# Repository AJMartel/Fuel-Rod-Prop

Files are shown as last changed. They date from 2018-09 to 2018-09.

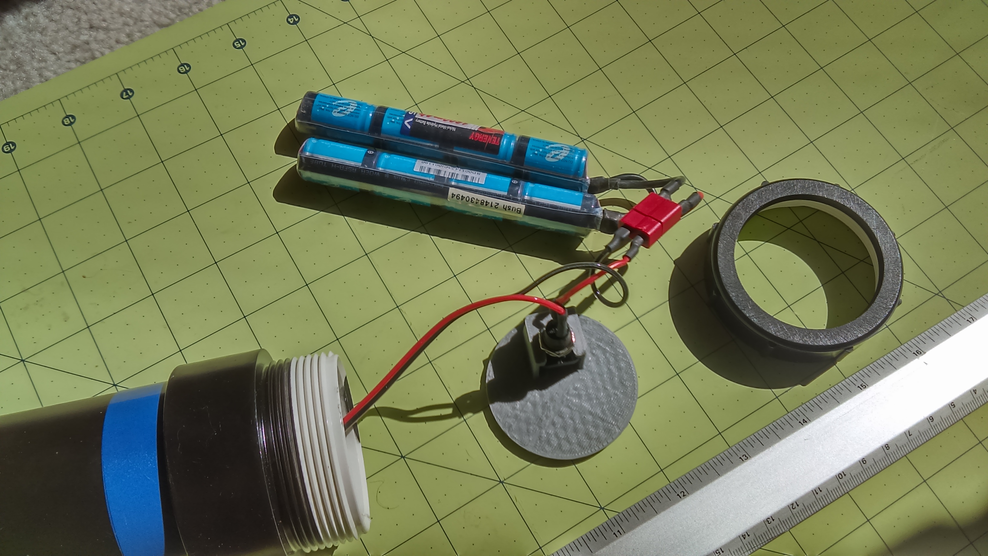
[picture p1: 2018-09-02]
IMAG0169.jpg

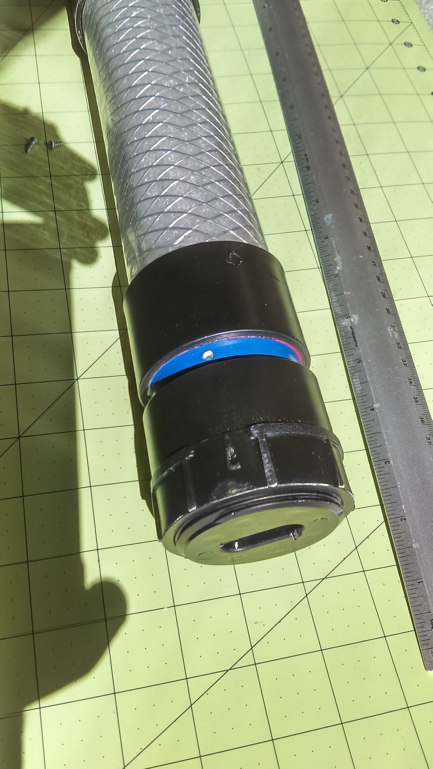
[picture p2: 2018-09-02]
IMAG0179.jpg

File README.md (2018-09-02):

# Fuel-Rod-Prop
An airsoft in game prop styled like a fuel rod.

This prop has 6 different modes of operation depending on what fits the game play best.

It responds to shock and beeps or displays different colored lighting. 

It can be used with the BoomBox prop as well to simulate fuel loading or unloading, if a multi-step goal is required for a game scenario.

The prop has no visible switches – the main power switch is a pushbutton that requires a 1-2”
pin to depress (thru a hole on the end). The unit senses shock and is programmed by
“tapping” it during program mode. Other magnetic sensors are used to “charge” the fuel or
discharge the fuel, and if the charging base isn't handy any high strength magnet can be used
to trip the internal reed switches. By using hidden magnetic switches, the unit is more rugged,
tamper-proof, and weather resistant. 

Note that this will probably not be improved upon or built (by me at least) again, but as i used several resources from others across the net when designing and constructing the device, i wanted to share the results with everyone as well.

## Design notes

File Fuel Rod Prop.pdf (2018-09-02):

Fuel Rod Prop Operation

The prop has no visible switches – the main power switch is a pushbutton that requires a 1-2” pin to depress (thru a hole on the end). The unit senses shock and is programmed by “tapping” it during program mode. Other magnetic sensors are used to “charge” the fuel or discharge the fuel, and if the charging base isn't handy any high strength magnet can be used to trip the internal reed switches. By using hidden magnetic switches, the unit is more rugged, tamper-proof, and weather resistant. Note that it is not waterproof however and should not be used in heavy rain or immersed.

If the unit is ever in heavy rain or immersed, be sure to unscrew the key switch end of the device and unplug the battery as soon as possible.

The unit will provide feedback when a hidden switch is tripped by LED color changes or beeper sounds.

If the fuel rod has been modified to work with the BoomBox, there will be an additional high strength magnet in the top (the longer black part) of the unit on the same side as the magnet sensor. This is used to tell the BoomBox the fuel rod is present.

Theory of operation

The prop is designed to mimic a “fuel rod” or a “mutagen container” from popular movies. It does not explode, but it does challenge the players in other ways depending on game mode:

1. The prop can require “charging” before it can be used.
2. The prop can “decay” once charged, requiring players to complete a task within a specific number of minutes (this is set in programming and not easily changed in the field). If the unit decays it must be recharged. As it decays the LEDs change from a green “charged” state to a blue “cold/dead” state.
3. The prop can become “unstable” if shaken or shocked too much. As the prop becomes more unstable it changes from Green to Red color.
4. The prop can be set to go inert if it is pushed into the unstable zone too many times. Once it goes inert, it must be recharged to be used.
5. The prop can be set to “lost” mode where it blinks and beeps once every couple seconds, making it harder to find at night or in a search and recover game mode.
6. The sensitivity can be set to different levels to make it more or less challenging to players.

If players have problems remembering what colors do what, just remind them that “GREEN IS GOOD”. Meaning a GREEN fuel rod is charged and not unstable or blown. BLUE is COLD, meaning not charged or primed (this isn’t necessarily bad, it depends on the game mode). RED is BAD, cause it means the device is exploded or abused.

Programming Modes

There are several game modes. The second mode is DEMO mode, where charging, decay, shaking and making it go inert can be demonstrated quickly. The third mode is a sensitivity setting mode, where the admin can bump or tap the prop harder or softer (or not at all) to set sensitivity to shock. All other modes differ in options – such as whether shaking can make it go inert or how long a decay takes, if decay is even enabled.

To enter program mode, turn on the device, let it initialize. It will quickly beep the number of times corresponding to the currently set game mode (i.e. 7 beeps = game mode 7, BoomBox Prop). The white LEDs will also show mode (in binary). After beeping stops, while the unit is still white, you can change the mode by tapping the unit. Each tap will advance in modes and beep the same number of times as the mode. The LED display will show (in binary) what number mode is active, with the power switch end as the lowest bit (right =1, middle=2, left =4, add the values to get your number).

Once you pass the last mode, the unit starts at mode 1 again. Once you reach the mode you want, leave the unit alone for 5 seconds and that mode will be set.

Note – This takes some practice to get used to. You should go thru the programming process a few times to get used to it. It is probably also in your best interest to hide the program modes and power switch from the players.

Mode Details

1. Resupply Safe Mode. Starts uncharged, Decays in 30 minutes, More than 5 red zones disables.
2. DEMO mode. Starts uncharged (BLUE). Place in charging base or hold magnet near charge sensor to 'charge' to GREEN. You have 1 minute to demonstrate the shock sensing (tap it to show it turning YELLOW then RED). As the time passes the unit decays from GREEN to BLUE. If you shake the unit enough it will become unstable and blink RED and flash and beep, then go inert (BLUE). You can recharge the unit if needed.
3. Sensitivity Setting. When the unit changes to 1 white LED color, you have 5 seconds to set the sensitivity by bumping the unit with harder or lighter force. Anything harder than how you bump the device will be seen as a valid shock and push the unit into instability. To set the unit to highest sensitivity, enter the sensitivity mode and do not bump or shock the prop at all.
4. Search N Rescue. Unit needs to be set to this mode (or powered up) then carefully set in the grass or on the ground, as it uses max sensitivity at first to detect being picked up. Unit beeps every so often to aid in location. When picked up, it senses this, and starts a countdown. Get the unit to a base to discharge it (or, deliver the goods before they expire). This mode might also be useful to give the BoomBox an initial charge. It will not, however, respond if used to disarm the BoomBox (but it will work for that).
5. Hot Potato – Unit starts charged, but cant be “discharged”. Unit counts down time and explodes, or explodes if mishandled more than 5 times. To prevent explosion, the unit must be placed in a base or can slot before it detonates. This resets the timer to the start of the countdown. In effect.. the players have to keep the unit from exploding by putting it in bases. Admins could move one base around the field agter it is used to prevent an explosion to make game play more active…
6. Rush – Unit starts charged. Players have to overtake the base, and insert the fuel rod. They must then hold the base for 5 minutes to allow the rod to explode. Once exploded, the rod resets when removed from the base and is ready to be used on the next objective. Instead of “exploding” you could tell the players the fuel rod is a hacking tool that takes 5 minutes to complete, and they must take each building (order does not matter) across the field.
7. BoomBox Prop – Unit starts charged. When placed in the BoomBox slot (or a base) it discharges and waits for removal. 10 seconds after removal, it is ready to take the charge back from the BoomBox by being placed back into the fuel rod slot. While the BoomBox is disabled at this point, the fuel rod will continue to alternate between charged and discharged state. An admin could start this mode, discharge the rod with a magnet, then start a scenario with a charged BoomBox in the process of counting down and give the special team the fuel rod discharged, and ask them to disarm the bomb, then bring back the fuel (the rod will be green if charge is recovered). Or just use it to start the BoomBox prop by giving a charged rod to players to take to the device…
Mode | Initial Charge State | Decay | Shock Mode | Name
1 | NOT Charged | 30 Minutes | 5 Red Zones disables it | ReSupply Risky
2 | NOT Charged | 1 Minute | 2 Red Zones disables it | Demo Mode Sensitive
3 | n/a | n/a | Starts at Max, tapping sets to that level. | Sensitivity Setting
4 | Charged | 30 Minutes | Reacts, but wont die. | Search n Rescue
5 | Charged | 30 Minutes | 5 Red Zones disables it | Hot Potato
6 | Charged | 5 Minutes | Reacts, but wont die. | Rush
7 | Charged | n/a | Reacts, but wont die. | BoomBox Prop

Battery Charging

The unit uses any LiPo or NiMh battery that will fit, from 7.2V to 12v. The battery connector is a normal Deans connector for reliability (but the current draw is at most 300mA which is fairly small). There is no protection against over discharge, so be careful when using LiPOs.

A NiMh 9.6V is recommended.

To open the unit, unscrew the key switch end and remove the battery carefully, trying not to damage or pull on wires and cables if possible. When reassembling, ensure wires and components are not pinched.

Fuse

The unit uses an internal small glass 1A fuse.

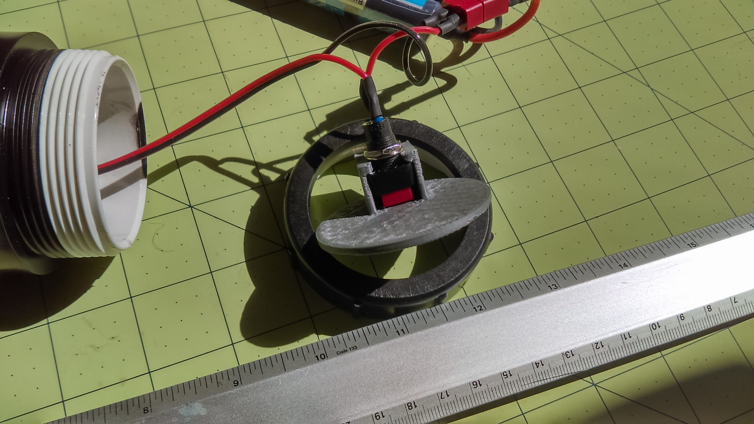
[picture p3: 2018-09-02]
IMAG0170.jpg

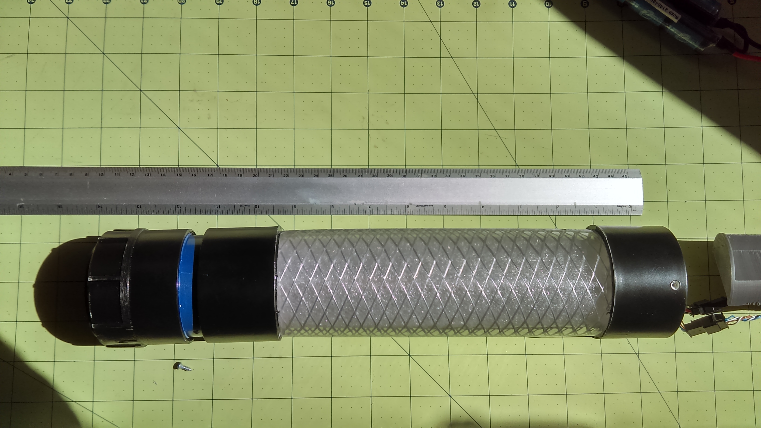
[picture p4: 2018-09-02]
IMAG0178.jpg

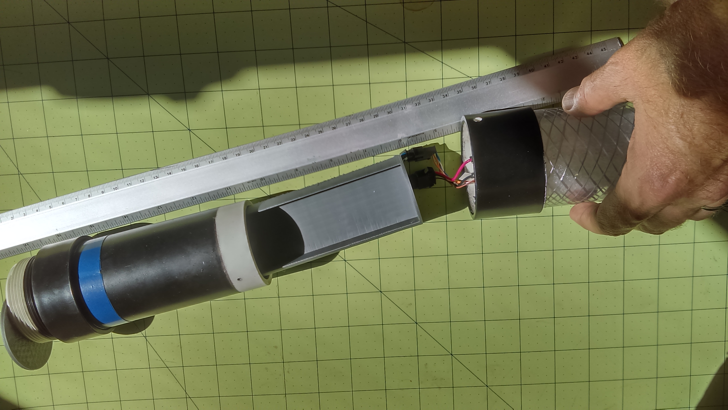
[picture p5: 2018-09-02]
IMAG0176.jpg

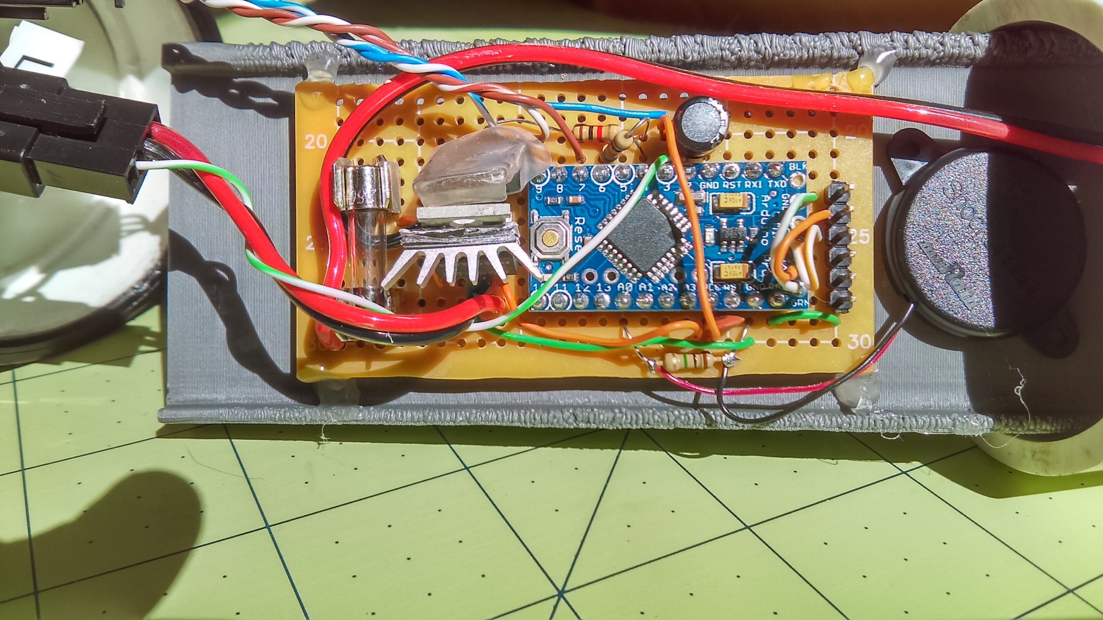
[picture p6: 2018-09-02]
IMAG0174.jpg

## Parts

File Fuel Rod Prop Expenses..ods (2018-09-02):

Item | Base Price | Qty | Amount | Total
Perfboard | 2.49 | 1 | $2.70 | $77.33
Black Paint (Fusion) | 4.94 | 0.3 | $1.60
Braided Vinyl Pipe | 8.98 | 0.5 | $4.86
2" DWV Coupling HXH 611942031900 | 1.26 | 1 | $1.36
2" PVC Coupling SXS 611942037643 | 1.96 | 1 | $2.12
2" DWV Male Adapter 611942032884 | 1.45 | 1 | $1.57
2" DWV Flush Cleanout Plug | 2.57 | 1 | $2.78
2" PVC Female Adapt | 1.88 | 1 | $2.04
NTE 74-5FG1A-B 1 Amp Fuse | 3.99 | 0.1 | $0.43
NTE 74-FC5-B Fuse Clips | 1.69 | 0.2 | $0.37
Philmore 30-100 Key Switch | 7.79 | 1 | $8.43
EvilMadScientist RGB LED Pixels | 10.99 | 0.9 | $10.71
Resistors (10k*2, 220*2, 1m) | 0.25 | 5 | $1.35
Arduino Pro Mini (Arducam) | 5.49 | 1 | $5.94
Screw Connectors | 0.5 | 4 | $2.17
10 ga Solid Wire |  | 1 | $-
Misc Connection Wire |  | 1 | $-
Solder |  | 1 | $-
Heat Shrink (1/2*2in, 1/4*4in) |  | 1 | $-
PVC Cement |  | 1 | $-
Screws |  | 1 | $-
SamariumCobalt Magnets (1 square, 2round) | 2 | 3 | $6.50
3D Print - Base, LED support top/bottom, keyswitch disc) ~75g-5h print time | 16 | 0.075 | $1.30
Piezo Sensor | 1 | 1 | $1.08
Reed Switches | 0.5 | 2 | $1.08
7.4v 1A-hr LiPo w/Deans | 15 | 1 | $16.24
Deans Male | 1.5 | 1 | $1.62
5V USB Power (Lighter Sicket, converted) | 1 | 1 | $1.08
Code Dev Time-Hours (actual * .3 factor for my non-expert skills? No idea what value is...) | 0 | 40 | $-
No documentation done yet. Code is unpublished, but commented.

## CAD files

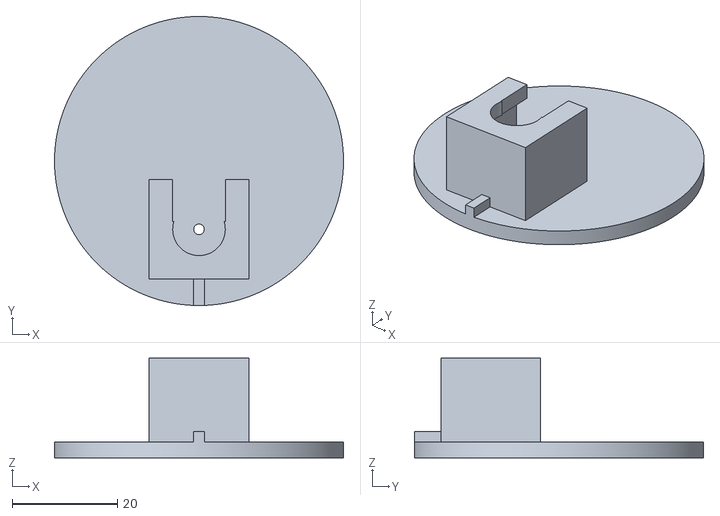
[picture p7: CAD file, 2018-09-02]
Fuel Rod Disc.stl
55.0 x 55.0 x 19.0

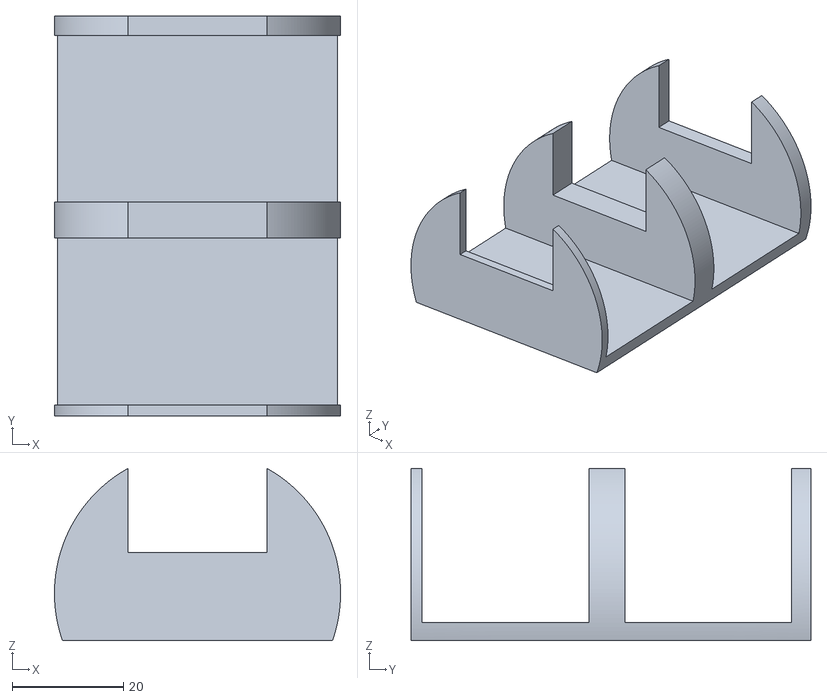
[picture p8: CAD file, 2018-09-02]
Fuel Rod Insert.stl
51.5 x 72.0 x 31.0

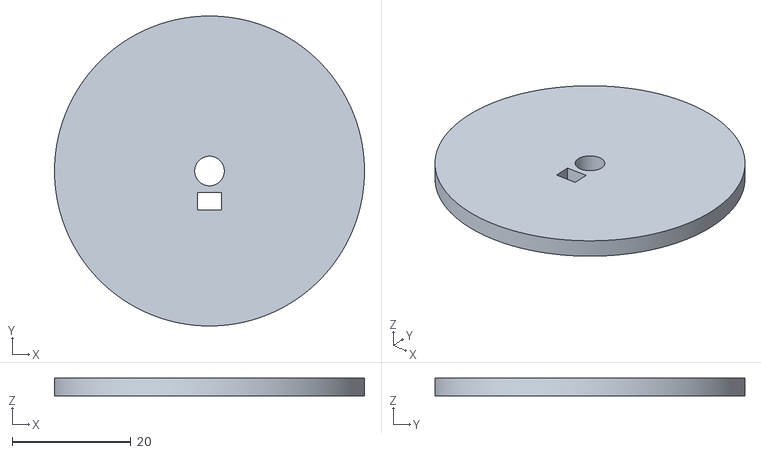
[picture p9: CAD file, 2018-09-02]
Fuel Rod Top LED Tube.stl
52.2 x 52.2 x 3.00

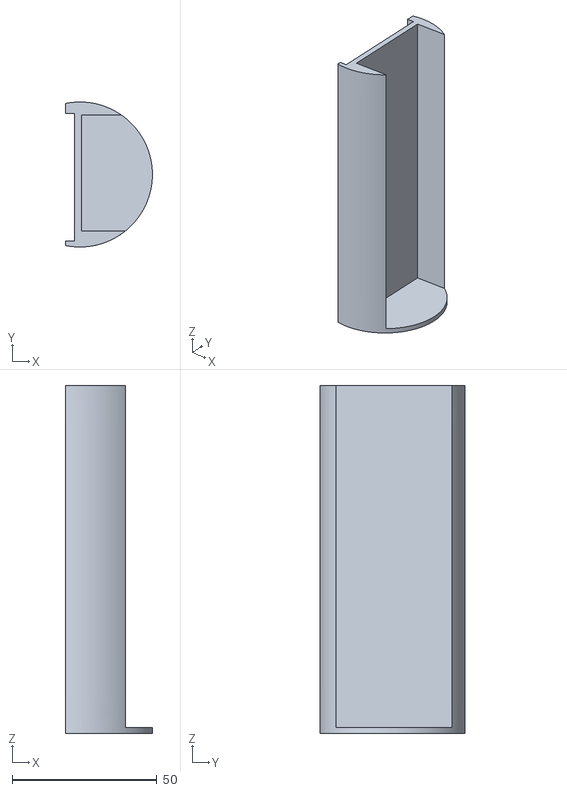
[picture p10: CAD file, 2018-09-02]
Fuel Rod NiMh Holder.stl
30.0 x 50.0 x 120.0

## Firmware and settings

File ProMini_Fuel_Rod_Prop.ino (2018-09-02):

/* Fuel Rod Prop Code v2.1
   Modes:
   1. ReSupply Risky. Uncharged, 30 minute decay, 5 Red events disables.
   2. Demo Mode, Uncharged, 1 m decay, 2 Red disables.
   3. Sensitivity Setting.
   4. Search N Rescue, Precharged, 30 m decay, 9999 Red events disables.
   5. Hot Potato, Precharged, 30 minute decay, 5 Red events disables.
   6. Rush, Precharged, 5 minute decay, 9999 Red events disables.
   7. BoomBox Prop, Precharged, 9999 no decay, 9999 Red events disables.
   
   Created: March 6, 2016
   Author: Reid Bush
*/
#include <WS2812.h>
#include <EEPROM.h>
const byte ledPIN = 2; // LED WS2812 on D2
const byte audioPIN = 4; // Audio Out on D4
const byte shakePIN = A0; // Shake Sensor on A0
const byte chargePIN = 6; // Charge Button on D6
const byte battPIN = A1; // Batt Sense on A1
byte gameMode = 1; // What game mode (see above) are we in?
byte instability = 0; // 0-255 0=calm 128=warn 250=red alert.
int redCount = 0; // How many red alerts we allow till fuel is tainted. Countdown style, default is 5.
int redLimit = 5; // How many red alerts we allow before discharging.
int threshold = 1; // Threshold for shake detection. 1=max sensitivity. Pull value from EEPROM initially.
int p = 20; // test charge loop delay
int s = 20; // test charge loop delay
byte eepromHigh = 0; // Value to hold EEPROM high byte.
byte eepromLow = 0; // Value to hold EEPROM low byte.
int decayTime = 0; // How long minutes we allow the fuel to last. 9999 = no decay.
unsigned long nextCalm = 0; // next millis to decrement instability.
unsigned long decayEndTime = 0; // Our fuel charge is decayed by this time.
unsigned long decayThirdTime = 0; // 1/3 Our fuel charge is decayed by this time.
unsigned long decay2ThirdTime = 0; // 2/3 Our fuel charge is decayed by this time.
unsigned long preProgTimeOut = 0; // Hold prog button until we reach this time to enter Prog Mode.
unsigned long nextFlash = 0; // Time when the next locate flash should occur.
bool countdown = false; // If on, we go from green to red and explode at end.
bool found = false; // true if the unit was found in S&R mode.
bool gameOn = false; // Is the game mode enabled?
bool charged = false; // Is the canister charged? (Green) or not (Blue)
bool redMode = false; // Are we in red mode?
bool needSensLearn = false; // Do we need to learn sensitivity again? default is to take last value from EEPROM.
bool progMode = false; // Are we in Prog mode?
bool led0Charged = false; // Track if LED0 can be shaken.
bool led1Charged = false; // Track if LED1 can be shaken.
WS2812 LED(3); // Set num of LEDs to 3
cRGB value;

void setup() {
  Serial.begin(9600);
  // Set up PIN functions.
  pinMode(audioPIN, OUTPUT);
  pinMode(shakePIN, OUTPUT);
  digitalWrite(shakePIN,LOW);
  pinMode(shakePIN, INPUT);
  pinMode(chargePIN, INPUT);
  pinMode(battPIN, INPUT);
  // Set remaining PINs to prevent quiescent current.
  pinMode(3, INPUT_PULLUP);
  pinMode(5, INPUT_PULLUP);
  pinMode(7, INPUT_PULLUP);
  pinMode(8, INPUT_PULLUP);
  pinMode(9, INPUT_PULLUP);
  pinMode(10, INPUT_PULLUP);
  pinMode(11, INPUT_PULLUP);
  pinMode(12, INPUT_PULLUP);
  pinMode(13, INPUT_PULLUP);
  pinMode(16, INPUT_PULLUP);
  pinMode(17, INPUT_PULLUP);
  // LED setup section.
  LED.setColorOrderRGB();
  LED.setOutput(ledPIN);
  // Get sensitivity setting from EEPROM if found.
  eepromHigh = EEPROM.read(0); 
  eepromLow = EEPROM.read(1);
  threshold = word(eepromHigh,eepromLow);
  if (threshold > 1024 || threshold < 1) {
    // value is invalid. May be corrupted or not initialzed yet. Default = 1
    threshold = 1;
    EEPROM.write(0,highByte(threshold));
    EEPROM.write(1,lowByte(threshold));
  }
  // Get last game setting from EEPROM if found.
  gameMode = EEPROM.read(2); 
  if (gameMode > 7 || gameMode < 1) {
    // value is invalid. May be corrupted or not initialzed yet. Default = 1
    gameMode = 1;
    EEPROM.write(2,gameMode);
  }
  // Notify that setup is complete.
  allLEDs(1);
  delay(200);
  allLEDs(0);
  Serial.println(F("Device is initialized."));
  Serial.println(F("Firmware 2.1"));
  Serial.print(F("Threshold: "));
  Serial.println(threshold);
  Serial.print(F("Game Mode:"));
  Serial.println(gameMode);
  preProgTimeOut = millis() + 10000; // We start the device in prog mode, and wait 10 seconds for a shock input to change modes.
  progMode = true;
  showMode(gameMode);
  for (int i = 0; i < gameMode; i++) {
    beep(80);
    delay(300);
  }
}


void loop() {
  // Program mode selection
  if (progMode) {
    int shakeValue = 0;
    shakeValue = analogRead(shakePIN);
    if (shakeValue > 10) { // something is bumping us, assume its a programming request.
      Serial.print("prog shake: ");
      Serial.println(shakeValue);
      gameMode ++;
      if (gameMode > 7) {
        gameMode = 1;
      }
      showMode(gameMode);
      for (int i = 0; i < gameMode; i++) {
        beep(80);
        delay(333);
        preProgTimeOut = millis() + 5000;
      }
    }
  }
      
  // No input pressed and we passed the Prog 10 sec timeout, set game values, exit progMode
  if (millis() > preProgTimeOut && progMode) { 
    progMode = false;
    preProgTimeOut = 0;
    decayEndTime = millis() + (decayTime * 60000);
    nextCalm = millis();
    instability = 0;
    // Common Variables set here. Change if needed for specific modes.
    countdown = false; // Rush mode 5 minute countdown to blow.
    needSensLearn = false;
    gameOn = true;
    EEPROM.write(2,gameMode);

    switch (gameMode) {
      case 1: // Resupply Risky Mode
        led0Charged = false;
        led1Charged = false;
        charged = false;
        decayTime = 30; // Normally 30
        redLimit = 5;
        Serial.println("Mode 1. ReSupply Safe.");
        break;
      case 2: // DEMO mode.
        led0Charged = false;
        led1Charged = false;
        charged = false;
        decayTime = 1;
        redLimit = 2;
        threshold = 1;
        Serial.println("Mode 2. DEMO.");
        break;
      case 3: // Sensitivity Set
        led0Charged = false;
        led1Charged = false;
        charged = false;
        decayTime = 9999;
        redLimit = 9999;
        needSensLearn = true;
        threshold = 1;
        gameOn = false;
        Serial.println("Mode 3. Sensitivity Set.");
        break;
      case 4:// Search & Rescue
        led0Charged = true;
        led1Charged = true;
        charged = true;
        decayTime = 30; // Normally 30
        redLimit = 9999;
        allLEDs(0);
        Serial.println("Mode 4. Search & Rescue.");
        break;
      case 5: // Hot Potato
        led0Charged = true;
        led1Charged = true;
        charged = true;
        decayTime = 30; // Normally 30
        redLimit = 5;
        allLEDs(4); // Green
        Serial.println("Mode 5. Hot Potato.");
        break;
      case 6: // Rush
        led0Charged = true;
        led1Charged = true;
        charged = true;
        allLEDs(4); // Green
        decayTime = 5;
        redLimit = 9999;
        Serial.println("Mode 6. Rush");
        break;
      case 7: // BoomBox Prop Mode
        led0Charged = true;
        led1Charged = true;
        charged = true;
        decayTime = 9999;
        redLimit = 9999;
        Serial.println("Mode 7. BoomBox Prop.");
        break;
    }
    redCount = redLimit;
    decayEndTime = millis() + (decayTime * 60000);
    decayThirdTime = millis() + (decayTime * 60000) / 3;
    decay2ThirdTime = millis() + (decayTime * 120000) / 3;
  }

  // Sensitivity setting requested (mode 2)
  if (needSensLearn) {
    learnShockLevel();
  }

  // Game mode processing
  if (gameOn) {
    switch (gameMode) {
      case 1: // Default Resupply Risky Mode uncharged, 5 red, 30m decay, discharges
        if (charged) {
          shakeProcess(); // Check for shaking and process
          if (redCount == 0) abused(1); // Check to see if device is abused and needs total discharge.
          decayLEDs(1); // Check for decay state and process
        } else {
          allLEDs(3); // Set LEDs blue
          if (digitalRead(chargePIN) == LOW) checkCharge(); // Check for charging base and process
        }
        break;
      case 2: // Demo Mode
        if (charged) {
          shakeProcess(); // Check for shaking and process
          if (redCount == 0) abused(1); // Check to see if device is abused and needs total discharge.
          decayLEDs(1); // Check for decay state and process
        } else {
          allLEDs(3); // Set LEDs blue
          if (digitalRead(chargePIN) == LOW) checkCharge(); // Check for charging base and process
        }
        break;
      case 4: // Search and Rescue Mode - 3 sec beep till shaken, then 25 mins decay till dies - in base wins.
        if (analogRead(shakePIN) > 2 && !found) { // something is bumping us, assume we have been picked up.
          Serial.println("Found! Starting countdown.");
          found = true;
          // alert that we are counting down.
          allLEDs(4); // Green
          beep(100);
          delay(100);
          beep(100);
          delay(100);
          beep(100);
          delay(100);
          beep(100);
          delay(100);
          decayEndTime = millis() + (decayTime * 60000);
          decayThirdTime = millis() + (decayTime * 60000) / 3;
          decay2ThirdTime = millis() + (decayTime * 120000) / 3;
        }
        if (millis() > nextFlash) {
          if (millis() > decayEndTime) {
            // Ran out of time.
            allLEDs(2);
            gameMode = false;
            charged = false;
          } else {
            allLEDs(3);
            beep(300);
            delay(100);
            allLEDs(4);
            beep(50);
            allLEDs(0);
            nextFlash = millis() + 3000;
            value.r = 0;
            value.g = 0;
            value.b = 254;
            if (millis() > decayThirdTime) {
              LED.set_crgb_at(0, value); // Set value at LED found at index 0
              LED.sync(); // Sends the data to the LEDs
              nextFlash = millis() + 2000;
            }
            if (millis() > decay2ThirdTime) {
              LED.set_crgb_at(1, value); // Set value at LED found at index 1
              LED.sync(); // Sends the data to the LEDs
              nextFlash = millis() + 1000;
            }
            if (millis() > (decayEndTime - 20000)) {
              nextFlash = millis() + 500;
            }
          }
        }
        if (digitalRead(chargePIN) == LOW) { // placed in base, WIN.
          allLEDs(4); // Green
          beep(100);
          delay(200);
          beep(100);
          delay(200);
          beep(100);
          delay(200);
          beep(100);
          delay(200);
          gameOn = false;
        }
        break;
      case 5: // Hot Potato Game Mode charged, 5 reds, 30 mins, base discharges, explodes
        // Starts green goes red as it decays, base must be used to neutralize
        shakeProcess(); // Check for shaking and process
        if (redCount == 0) {
          abused(2); // Check to see if device is abused and needs to explode.
          allLEDs(2);
          gameOn = false;
        }
        decayLEDs(2); // Check for decay state and process
        if (digitalRead(chargePIN) == HIGH && !charged) {
          // Not in charge base, discharged, set it off
          abused(2);
          allLEDs(2);
          gameOn = false;
        }
        if (digitalRead(chargePIN) == LOW) {
          abused(1); // Check for charging base and discharge if found.
          led0Charged = true;
          led1Charged = true;
          charged = true;
          allLEDs(4); // Green
          redCount = redLimit;
          decayEndTime = millis() + (decayTime * 60000);
          decayThirdTime = millis() + (decayTime * 60000) / 3;
          decay2ThirdTime = millis() + (decayTime * 120000) / 3;
        }
        break;
      case 6: // Rush Game Mode
        //shakeProcess(); // shake but never disable
        if (digitalRead(chargePIN) == LOW) {
          // In base, 5 min countdown to blow.
          if (countdown) {
            // already in countdown mode
            decayLEDs(2);
            if (millis() > nextFlash) {
              beep(100);
              nextFlash = millis() + 3000;
              if (millis() > decayThirdTime) {
                nextFlash = millis() + 1000;
              }
              if (millis() > decay2ThirdTime) {
                nextFlash = millis() + 500;
              }
            }
            if (millis() > decayEndTime) {
              abused(2); //BOOM
              led0Charged = true;
              led1Charged = true;
              charged = true;
              allLEDs(4); // Green
              redCount = redLimit;
              decayEndTime = millis() + (decayTime * 60000);
              decayThirdTime = millis() + (decayTime * 60000) / 3;
              decay2ThirdTime = millis() + (decayTime * 120000) / 3;
            }
          } else { // Start Countdown mode.
            countdown = true;
            nextFlash = millis() + 5000;
            decayEndTime = millis() + (decayTime * 60000);
            decayThirdTime = millis() + (decayTime * 60000) / 3;
            decay2ThirdTime = millis() + (decayTime * 120000) / 3;
            beep(100);
            value.r = 255;
            value.g = 255;
            value.b = 0;
            LED.set_crgb_at(0, value); // Set value at LED found at index 0
            LED.set_crgb_at(1, value); // Set value at LED found at index 1
            LED.set_crgb_at(2, value); // Set value at LED found at index 2
            LED.sync(); // Sends the data to the LEDs
          }
        } else {
          // Not in base, back to green and countdown reset.
          if (countdown) {
            Serial.println("Mode 6. Rush - exiting countdown.");
            led0Charged = true;
            led1Charged = true;
            charged = true;
            allLEDs(4);
            countdown = false;
          }
        }
        break;
      case 7: // BoomBox Charged, No decay, No explode
        if (charged) { // Charged
          shakeProcess(); // Check for shaking and process
          if (digitalRead(chargePIN) == LOW) {
            abused(1); // Process discharge.
            allLEDs(3); // Set LEDS Blue
            while (digitalRead(chargePIN) == LOW) {
              // Waiting to be removed from can slot or base.
              delay(1);
            }
            delay(10000); // Wait 10 secs to ensure it wasnt just bumped.
          }
        } else { // Not Charged
          if (digitalRead(chargePIN) == LOW) {
            checkCharge(); // Process charge
            allLEDs(4); // Set LEDs Green
            while (digitalRead(chargePIN) == LOW) {
              // Waiting to be removed from can slot or base.
              delay(1);
            }
            delay(10000); // Wait 10 secs to ensure it wasnt just bumped.
          }
        }
        break;
    }
  } // End game mode processing
} // End main loop

void decayLEDs(byte decayMode) { // decayMode -1 normal decay to blue 2 decay to red.
    if (decayTime != 9999 && charged) {
    if (decayMode == 1) {
      value.r = 0;
      value.g = 0;
      value.b = 254;
    } else {
      value.r = 254;
      value.g = 0;
      value.b = 0;
    }
    if (millis() > decayThirdTime && led0Charged) {
      led0Charged = false;
      LED.set_crgb_at(0, value); // Set value at LED found at index 0
      LED.sync(); // Sends the data to the LEDs
      beep(100);
      Serial.println("1/3 of charge depleted.");
    }
    if (millis() > decay2ThirdTime && led1Charged) {
      led1Charged = false;
      LED.set_crgb_at(1, value); // Set value at LED found at index 1
      LED.sync(); // Sends the data to the LEDs
      beep(100);
      Serial.println("2/3 of charge depleted.");
    }
    if (millis() > decayEndTime && charged) {
      charged = false;
      beep(600);
      Serial.println("Charge depleted.");
    }
  }
}

void abused(byte abuseMode) { 
  Serial.println("Red Alert triggered.");
  led0Charged = false;
  led1Charged = false;
  charged = false;
  instability = 0;
  redCount = redLimit;
  if (abuseMode == 1) { // Discharge to blue
    value.r = 0;
    value.b = 128;
    for (p = 2; p < 16; p++) {
      beep(50);
      for(s = 0; s < 250; s++) {
        value.g = s;
        LED.set_crgb_at(0, value); // Set value at LED found at index 0
        LED.set_crgb_at(1, value); // Set value at LED found at index 1
        LED.set_crgb_at(2, value); // Set value at LED found at index 2
        LED.sync(); // Sends the data to the LEDs
        delay(p);
        s=s+(20-p);
      }
      beep(100);
      for(s = 250; s > 2; s--) {
        value.g = s;
        LED.set_crgb_at(0, value); // Set value at LED found at index 0
        LED.set_crgb_at(1, value); // Set value at LED found at index 1
        LED.set_crgb_at(2, value); // Set value at LED found at index 2
        LED.sync(); // Sends the data to the LEDs
        delay(p);
        s=s-(20-p);
      }
    }
    allLEDs(4); // Blue
  } else { // Explode to Red
    value.g = 0;
    value.b = 0;
    for (p = 16; p > 2; p--) {
      beep(100);
      for(s = 0; s < 250; s++) {
        value.r = s;
        LED.set_crgb_at(0, value); // Set value at LED found at index 0
        LED.set_crgb_at(1, value); // Set value at LED found at index 1
        LED.set_crgb_at(2, value); // Set value at LED found at index 2
        LED.sync(); // Sends the data to the LEDs
        delay(p);
        s=s+(20-p);
      }
      beep(100);
      for(s = 250; s > 2; s--) {
        value.r = s;
        LED.set_crgb_at(0, value); // Set value at LED found at index 0
        LED.set_crgb_at(1, value); // Set value at LED found at index 1
        LED.set_crgb_at(2, value); // Set value at LED found at index 2
        LED.sync(); // Sends the data to the LEDs
        delay(p);
        s=s-(20-p);
      }
    }
    allLEDs(2); // Red
    beep(5000);
    delay(5000);
    allLEDs(0); // Off
  }
}

void allLEDs(byte mode) { //0=off, 1=white, 2=Red, 3=Blue, 4=Green
  // We set all LEDs to one color a lot, so write a function to do that.
  value.r = 0;
  value.g = 0;
  value.b = 0;
  switch (mode) {
    case 1:
      value.r = 255;
      value.g = 255;
      value.b = 255;
    break;
    case 2:
      value.r = 255;
    break;
    case 3:
      value.b = 255;
    break;
    case 4:
      value.g = 255;
    break;
  }
  LED.set_crgb_at(0, value); // Set value at LED found at index 0
  LED.set_crgb_at(1, value); // Set value at LED found at index 1
  LED.set_crgb_at(2, value); // Set value at LED found at index 2
  LED.sync(); // Sends the data to the LEDs
  delay(2);
}

void shakeProcess() {
  // Process Shake Sensor
  if (analogRead(shakePIN) > threshold) {
    Serial.print("Instability/Shake Sense: ");
    Serial.print(instability);
    Serial.print(" / ");
    Serial.println(analogRead(shakePIN));
    if (instability >= 220) { // Redmode
      instability = 220;
      beep(200);
      if (!redMode) {
        redMode = true;
        redCount--;
      }
    } else {
      instability += 10;
    }
    value.b = 0;
    value.r = instability; // Amount of red = amount of instability.
    value.g = 220 - instability; // Amount of green = inverse of red.
    if (led0Charged) {
      LED.set_crgb_at(0, value); // Set value at LED found at index 0 if its still charged.
    }
    if (led1Charged) {
      LED.set_crgb_at(1, value); // Set value at LED found at index 1 if its still charged.
    }
    LED.set_crgb_at(2, value); // Set value at LED found at index 2
    LED.sync(); // Sends the data to the LEDs
    delay(2);
  }
  if (millis() > nextCalm) {
    if (instability <= 3) {
      instability = 0;
    } else {
      instability --;
    }
    nextCalm = millis() + 40;
    value.b = 0;
    value.r = instability;
    value.g = 220 - instability;
    if (led0Charged) {
      LED.set_crgb_at(0, value); // Set value at LED found at index 0
    }
    if (led1Charged) {
      LED.set_crgb_at(1, value); // Set value at LED found at index 1
    }
    LED.set_crgb_at(2, value); // Set value at LED found at index 2
    LED.sync();
    delay(2);
    if (instability > 220) {
      beep(400);
    }
    if (redMode && (instability < 220)) { // We are leaving redMode.
      redMode = false;
    }
  }
}
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

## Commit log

2018-09-02 Create README.md
    Readme created with prop information.
2018-09-02 Main initial project file upload
    All the files i can find to upload on the project. Looking for a schematic still. Most of the code is commented however so the Pro Mini (Arduino) i used on the project is at least easy to figure out 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
    [Fuel Rod Disc.stl, Fuel Rod Insert.stl, Fuel Rod NiMh Holder.stl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]
